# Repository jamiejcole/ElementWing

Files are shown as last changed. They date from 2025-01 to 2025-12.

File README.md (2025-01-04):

## Element Wing - A DIY Command Wing for ETC EOS
This project is an extension of [my previous](https://github.com/jamiejcole/zenith) EOS controller that I made primarily for controlling moving head fixtures, as my Element 2 console doesn't have any encoder wheels.

It's a full sized EOS command wing, featuring the standard ETC key layout and 4 customisable rotary encoders.

Top

### Components used
| Part | Qty | Total ($AUD) | Source |
| --- | --- | --- | --- |
| Gateron Black Switches | 90  | $31.19 | https://www.aliexpress.com/item/1005006376024657.html |
| Blank White XDA PBT Keycaps | 90  | $34.00 | https://www.aliexpress.com/item/1005007683242914.html |
| 1N1418 THT Diodes | 90  | $4.69 | https://www.aliexpress.com/item/32866531235.html |
| MCP23017-E/SO | 1 | $12.59 | https://www.aliexpress.com/item/1005005066054098.html |
| Raspberry Pi Pico* | 1 | $5.63 | https://www.aliexpress.com/item/1005006071676557.html |
| EC11 Rotary Encoders | 4 | $5.20 | https://www.aliexpress.com/item/10000056483250.html |
| Aluminium Knob for Encoders | 4 | $11.39 | https://www.aliexpress.com/item/1005005207623966.html |
| Plastic Heat Set Inserts | 6 | $14.99 | https://www.aliexpress.com/item/1005006472962973.html |
| **Total (excluding PCB)** | | **$119.68**  | |

> Note: The PCB design has the footprint for an official Raspberry Pi Pico with a micro-usb port. I wanted to have USB-C on my board, so I ordered the 16M variant of the above RP2040 board, without checking the pin layout. The board I ordered actually had a slightly different pin layout to the official Pi Pico so I had to make some jumps with short wire on the board, so if you use my PCB design, check which Pico you're ordering first!

## PCB Design
This was the first PCB I've designed, so apologies in advanced if I've made any silly mistakes on it. [Joe Scotto's video](https://www.youtube.com/watch?v=8WXpGTIbxlQ) was helpful for getting started with the design, and [iNimbleSloth's tutorials](https://www.youtube.com/watch?v=XKWoeBwpVNg) were also extremely useful for designing the keyswitch matrix. I ended up ordering the PCB from [JLCPCB](https://jlcpcb.com/) for around $100AUD including shipping, bringing the **total project cost to ~$220 AUD**.

PCB

The PCB consists of a 13x8 diode keyswitch matrix, where each row and column are connected to a GPIO pin on the Pico. The A/B/SW pins of each encoder are connected to a GPIO port on the MCP23017, which is connected to the Pico on the I2C0 interface, with the SDA and SCL lines pulled up to 3v3 with 2.2k resistors.

### Assembly process
After receiving the PCBs, I started designing some test layouts for the Cherry MX style switches. Due to the bed size of my 3D printer, I had to split up each piece into two parts, to be plastic welded together after printing. The CAD design consists of three main parts (each with left/right sides):
1. A plate for the switches to be inserted into prior to soldering to the PCB
2. A main case where the brass heat-set inserts will be put in, allowing the whole unit to be bolted together.
3. A top face-plate/cover with cut-outs for the switches and encoders.

Exploded View

### Custom Keycaps
The keycaps were made using a process I [found here](https://www.youtube.com/watch?v=JR1BwcFyexQ). I used blank white XDA profile PBT keycaps from aliexpress. The process was pretty straightforward:
- Cover each keycap in a thin layer of powder from a toner cartridge. I breathed on the keys before dunking them in the powder (the "hah hah" kind of breathing you do to clean glasses) to get the powder to stick better, then gently blew off the excess.
- Place keycap into a jig mounted to the laser engraver (this was done to ensure the text is consistently in the correct spot).
- Using a 15W diode laser at 380mm/min, 2.1% power and text on a fill layer at 300 lines/inch, etched the dye into the keycaps.
- Cleaned off the excess powder with warm water.




### Programming the microcontroller
I decided to use a Raspberry Pi Pico rather than an Arduino or ESP8266 due to the amount of GPIO pins it had. I downloaded [Earle Philhower's Arduino Core](https://github.com/earlephilhower/arduino-pico) for RP2040 boards and uploaded a test sketch using the Arduino IDE. The Pico uses OSC to communicate with EOS over the USB Serial interface. More info about OSC [can be found here](https://github.com/cnmat/osc). 

The [ETC #lighthack](https://github.com/ETCLabs/lighthack) community also was extremely helpful. Big thanks to [sstaub](https://github.com/CNMAT/OSC/issues/159#issuecomment-2566483844) over on the OSC repo.

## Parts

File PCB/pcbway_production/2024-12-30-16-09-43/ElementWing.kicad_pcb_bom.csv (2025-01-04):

Designator | Quantity | Value | Footprint | Package | MPN | DNP | Mount_Type | Description | Sim.Device | Sim.Pins
D1, D10, D11, D12, D13, D14, D15, D16, D17, D18, D19, D2, D20, D21, D22, D23, D24, D25, D26, D27, D28, D29, D3, D30, D31, D32, D33, D34, D35, D36, D37, D38, D39, D4, D40, D41, D42, D43, D44, D45, D46, D47, D48, D49, D5, D50, D51, D52, D53, D54, D55, D56, D57, D58, D59, D6, D60, D61, D62, D63, D64, D65, D66, D67, D68, D69, D7, D70, D71, D72, D73, D74, D75, D76, D77, D78, D79, D8, D80, D81, D82, D83, D84, D85, D86, D87, D88, D89, D9, D90 | 90 | Diode | Diode_DO-35 |  |  |  | tht | 1N4148 (DO-35) or 1N4148W (SOD-123) | D | 1=K 2=A
EC1, EC2, EC3, EC4 | 4 | RotaryEncoder_Switch | RotaryEncoder_Alps_EC11E-Switch_Vertical_H20mm |  |  |  | tht | Rotary encoder, dual channel, incremental quadrate outputs, with switch
R1, R2 | 2 | 2.2k | R_Axial_DIN0207_L6.3mm_D2.5mm_P10.16mm_Horizontal |  |  |  | tht | Resistor
SW1 | 1 | Displays | MX_PCB_1.00u |  |  |  | tht | Push button switch, normally open, two pins, 45° tilted
SW10 | 1 | MoreSK | MX_PCB_1.00u |  |  |  | tht | Push button switch, normally open, two pins, 45° tilted
SW11 | 1 | Live | MX_PCB_1.00u |  |  |  | tht | Push button switch, normally open, two pins, 45° tilted
SW12 | 1 | Blind | MX_PCB_1.00u |  |  |  | tht | Push button switch, normally open, two pins, 45° tilted
SW13 | 1 | ScrollLock | MX_PCB_1.00u |  |  |  | tht | Push button switch, normally open, two pins, 45° tilted
SW14 | 1 | Macro | MX_PCB_1.00u |  |  |  | tht | Push button switch, normally open, two pins, 45° tilted
SW15 | 1 | Help | MX_PCB_1.00u |  |  |  | tht | Push button switch, normally open, two pins, 45° tilted
SW16 | 1 | Learn | MX_PCB_1.00u |  |  |  | tht | Push button switch, normally open, two pins, 45° tilted
SW17 | 1 | Query | MX_PCB_1.00u |  |  |  | tht | Push button switch, normally open, two pins, 45° tilted
SW18 | 1 | CopyTo | MX_PCB_1.00u |  |  |  | tht | Push button switch, normally open, two pins, 45° tilted
SW19 | 1 | RecallFrom | MX_PCB_1.00u |  |  |  | tht | Push button switch, normally open, two pins, 45° tilted
SW2 | 1 | AddressPatch | MX_PCB_1.00u |  |  |  | tht | Push button switch, normally open, two pins, 45° tilted
SW20 | 1 | LabelNote | MX_PCB_1.00u |  |  |  | tht | Push button switch, normally open, two pins, 45° tilted
SW21 | 1 | EmptyMacro | MX_PCB_1.00u |  |  |  | tht | Push button switch, normally open, two pins, 45° tilted
SW22 | 1 | About | MX_PCB_1.00u |  |  |  | tht | Push button switch, normally open, two pins, 45° tilted
SW23 | 1 | Park | MX_PCB_1.00u |  |  |  | tht | Push button switch, normally open, two pins, 45° tilted
SW24 | 1 | Escape | MX_PCB_1.00u |  |  |  | tht | Push button switch, normally open, two pins, 45° tilted
SW25 | 1 | PageUp | MX_PCB_1.00u |  |  |  | tht | Push button switch, normally open, two pins, 45° tilted
SW26 | 1 | Select | MX_PCB_1.00u |  |  |  | tht | Push button switch, normally open, two pins, 45° tilted
SW27 | 1 | Delete | MX_PCB_1.00u |  |  |  | tht | Push button switch, normally open, two pins, 45° tilted
SW28 | 1 | Path | MX_PCB_1.00u |  |  |  | tht | Push button switch, normally open, two pins, 45° tilted
SW29 | 1 | Effect | MX_PCB_1.00u |  |  |  | tht | Push button switch, normally open, two pins, 45° tilted
SW3 | 1 | MLControls | MX_PCB_1.00u |  |  |  | tht | Push button switch, normally open, two pins, 45° tilted
SW30 | 1 | GoToCue | MX_PCB_1.00u |  |  |  | tht | Push button switch, normally open, two pins, 45° tilted
SW31 | 1 | Block | MX_PCB_1.00u |  |  |  | tht | Push button switch, normally open, two pins, 45° tilted
SW32 | 1 | Assert | MX_PCB_1.00u |  |  |  | tht | Push button switch, normally open, two pins, 45° tilted
SW33 | 1 | Undo | MX_PCB_1.00u |  |  |  | tht | Push button switch, normally open, two pins, 45° tilted
SW34 | 1 | High | MX_PCB_1.00u |  |  |  | tht | Push button switch, normally open, two pins, 45° tilted
SW35 | 1 | Fan | MX_PCB_1.00u |  |  |  | tht | Push button switch, normally open, two pins, 45° tilted
SW36 | 1 | Capture | MX_PCB_1.00u |  |  |  | tht | Push button switch, normally open, two pins, 45° tilted
SW37 | 1 | PageLeft | MX_PCB_1.00u |  |  |  | tht | Push button switch, normally open, two pins, 45° tilted
SW38 | 1 | PageDown | MX_PCB_1.00u |  |  |  | tht | Push button switch, normally open, two pins, 45° tilted
SW39 | 1 | PageRight | MX_PCB_1.00u |  |  |  | tht | Push button switch, normally open, two pins, 45° tilted
SW4 | 1 | S1 | MX_PCB_1.00u |  |  |  | tht | Push button switch, normally open, two pins, 45° tilted
SW40 | 1 | Part | MX_PCB_1.00u |  |  |  | tht | Push button switch, normally open, two pins, 45° tilted
SW41 | 1 | Cue | MX_PCB_1.00u |  |  |  | tht | Push button switch, normally open, two pins, 45° tilted
SW42 | 1 | Record | MX_PCB_1.00u |  |  |  | tht | Push button switch, normally open, two pins, 45° tilted
SW43 | 1 | + | MX_PCB_1.00u |  |  |  | tht | Push button switch, normally open, two pins, 45° tilted
SW44 | 1 | Thru | MX_PCB_1.00u |  |  |  | tht | Push button switch, normally open, two pins, 45° tilted
SW45 | 1 | - | MX_PCB_1.00u |  |  |  | tht | Push button switch, normally open, two pins, 45° tilted
SW46 | 1 | / | MX_PCB_1.00u |  |  |  | tht | Push button switch, normally open, two pins, 45° tilted
SW47 | 1 | Mark | MX_PCB_1.00u |  |  |  | tht | Push button switch, normally open, two pins, 45° tilted
SW48 | 1 | Sneak | MX_PCB_1.00u |  |  |  | tht | Push button switch, normally open, two pins, 45° tilted
SW49 | 1 | SelectLast | MX_PCB_1.00u |  |  |  | tht | Push button switch, normally open, two pins, 45° tilted
SW5 | 1 | S2 | MX_PCB_1.00u |  |  |  | tht | Push button switch, normally open, two pins, 45° tilted
SW50 | 1 | IntensityPalette | MX_PCB_1.00u |  |  |  | tht | Push button switch, normally open, two pins, 45° tilted
SW51 | 1 | FocusPalette | MX_PCB_1.00u |  |  |  | tht | Push button switch, normally open, two pins, 45° tilted
SW52 | 1 | RecordOnly | MX_PCB_1.00u |  |  |  | tht | Push button switch, normally open, two pins, 45° tilted
SW53 | 1 | num7 | MX_PCB_1.00u |  |  |  | tht | Push button switch, normally open, two pins, 45° tilted
SW54 | 1 | num8 | MX_PCB_1.00u |  |  |  | tht | Push button switch, normally open, two pins, 45° tilted
SW55 | 1 | num9 | MX_PCB_1.00u |  |  |  | tht | Push button switch, normally open, two pins, 45° tilted
SW56 | 1 | RemDim | MX_PCB_1.00u |  |  |  | tht | Push button switch, normally open, two pins, 45° tilted
SW57 | 1 | +% | MX_PCB_1.00u |  |  |  | tht | Push button switch, normally open, two pins, 45° tilted
SW58 | 1 | Home | MX_PCB_1.00u |  |  |  | tht | Push button switch, normally open, two pins, 45° tilted
SW59 | 1 | SelectManual | MX_PCB_1.00u |  |  |  | tht | Push button switch, normally open, two pins, 45° tilted
SW6 | 1 | S3 | MX_PCB_1.00u |  |  |  | tht | Push button switch, normally open, two pins, 45° tilted
SW60 | 1 | ColorPalette | MX_PCB_1.00u |  |  |  | tht | Push button switch, normally open, two pins, 45° tilted
SW61 | 1 | BeamPalette | MX_PCB_1.00u |  |  |  | tht | Push button switch, normally open, two pins, 45° tilted
SW62 | 1 | Update | MX_PCB_1.00u |  |  |  | tht | Push button switch, normally open, two pins, 45° tilted
SW63 | 1 | num4 | MX_PCB_1.00u |  |  |  | tht | Push button switch, normally open, two pins, 45° tilted
SW64 | 1 | num5 | MX_PCB_1.00u |  |  |  | tht | Push button switch, normally open, two pins, 45° tilted
SW65 | 1 | num6 | MX_PCB_1.00u |  |  |  | tht | Push button switch, normally open, two pins, 45° tilted
SW66 | 1 | Out | MX_PCB_1.00u |  |  |  | tht | Push button switch, normally open, two pins, 45° tilted
SW67 | 1 | -% | MX_PCB_1.00u |  |  |  | tht | Push button switch, normally open, two pins, 45° tilted
SW68 | 1 | Trace | MX_PCB_1.00u |  |  |  | tht | Push button switch, normally open, two pins, 45° tilted
SW69 | 1 | SelectActive | MX_PCB_1.00u |  |  |  | tht | Push button switch, normally open, two pins, 45° tilted
SW7 | 1 | S4 | MX_PCB_1.00u |  |  |  | tht | Push button switch, normally open, two pins, 45° tilted
SW70 | 1 | Preset | MX_PCB_1.00u |  |  |  | tht | Push button switch, normally open, two pins, 45° tilted
SW71 | 1 | Sub | MX_PCB_1.00u |  |  |  | tht | Push button switch, normally open, two pins, 45° tilted
SW72 | 1 | Group | MX_PCB_1.00u |  |  |  | tht | Push button switch, normally open, two pins, 45° tilted
SW73 | 1 | num1 | MX_PCB_1.00u |  |  |  | tht | Push button switch, normally open, two pins, 45° tilted
SW74 | 1 | num2 | MX_PCB_1.00u |  |  |  | tht | Push button switch, normally open, two pins, 45° tilted
SW75 | 1 | num3 | MX_PCB_1.00u |  |  |  | tht | Push button switch, normally open, two pins, 45° tilted
SW76 | 1 | Full | MX_PCB_1.00u |  |  |  | tht | Push button switch, normally open, two pins, 45° tilted
SW77 | 1 | Level | MX_PCB_1.00u |  |  |  | tht | Push button switch, normally open, two pins, 45° tilted
SW78 | 1 | QOnlyTrack | MX_PCB_1.00u |  |  |  | tht | Push button switch, normally open, two pins, 45° tilted
SW79 | 1 | Last | MX_PCB_1.00u |  |  |  | tht | Push button switch, normally open, two pins, 45° tilted
SW8 | 1 | S5 | MX_PCB_1.00u |  |  |  | tht | Push button switch, normally open, two pins, 45° tilted
SW80 | 1 | Shift | MX_PCB_1.00u |  |  |  | tht | Push button switch, normally open, two pins, 45° tilted
SW81 | 1 | Delay | MX_PCB_1.00u |  |  |  | tht | Push button switch, normally open, two pins, 45° tilted
SW82 | 1 | Time | MX_PCB_1.00u |  |  |  | tht | Push button switch, normally open, two pins, 45° tilted
SW83 | 1 | clear | MX_PCB_1.00u |  |  |  | tht | Push button switch, normally open, two pins, 45° tilted
SW84 | 1 | num0 | MX_PCB_1.00u |  |  |  | tht | Push button switch, normally open, two pins, 45° tilted
SW85 | 1 | num. | MX_PCB_1.00u |  |  |  | tht | Push button switch, normally open, two pins, 45° tilted
SW86 | 1 | At | MX_PCB_1.00u |  |  |  | tht | Push button switch, normally open, two pins, 45° tilted
SW87 | 1 | Enter | MX_PCB_1.00u |  |  |  | tht | Push button switch, normally open, two pins, 45° tilted
SW88 | 1 | Next | MX_PCB_1.00u |  |  |  | tht | Push button switch, normally open, two pins, 45° tilted
SW89 | 1 | StopBack | MX_PCB_1.00u |  |  |  | tht | Push button switch, normally open, two pins, 45° tilted
SW9 | 1 | S6 | MX_PCB_1.00u |  |  |  | tht | Push button switch, normally open, two pins, 45° tilted
SW90 | 1 | Go | MX_PCB_1.00u |  |  |  | tht | Push button switch, normally open, two pins, 45° tilted
U1 | 1 | Raspberry_Pi_Pico | Raspberry_Pi_Pico |  |  |  | tht
U2 | 1 | MCP23017_SO | SOIC-28W_7.5x17.9mm_P1.27mm |  |  |  | smt | 16-bit I/O expander, I2C, interrupts, w pull-ups, SOIC-28

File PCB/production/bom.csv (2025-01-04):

Designator | Footprint | Quantity | Value | LCSC Part #
D1, D10, D11, D12, D13, D14, D15, D16, D17, D18, D19, D2, D20, D21, D22, D23, D24, D25, D26, D27, D28, D29, D3, D30, D31, D32, D33, D34, D35, D36, D37, D38, D39, D4, D40, D41, D42, D43, D44, D45, D46, D47, D48, D49, D5, D50, D51, D52, D53, D54, D55, D56, D57, D58, D59, D6, D60, D61, D62, D63, D64, D65, D66, D67, D68, D69, D7, D70, D71, D72, D73, D74, D75, D76, D77, D78, D79, D8, D80, D81, D82, D83, D84, D85, D86, D87, D88, D89, D9, D90 | Diode_DO-35 | 90 | Diode
EC1, EC2, EC3, EC4 | RotaryEncoder_Alps_EC11E-Switch_Vertical_H20mm | 4 | RotaryEncoder_Switch
R1, R2 | R_Axial_DIN0207_L6.3mm_D2.5mm_P10.16mm_Horizontal | 2 | 2.2k
SW1 | MX_PCB_1.00u | 1 | Displays
SW10 | MX_PCB_1.00u | 1 | MoreSK
SW11 | MX_PCB_1.00u | 1 | Live
SW12 | MX_PCB_1.00u | 1 | Blind
SW13 | MX_PCB_1.00u | 1 | ScrollLock
SW14 | MX_PCB_1.00u | 1 | Macro
SW15 | MX_PCB_1.00u | 1 | Help
SW16 | MX_PCB_1.00u | 1 | Learn
SW17 | MX_PCB_1.00u | 1 | Query
SW18 | MX_PCB_1.00u | 1 | CopyTo
SW19 | MX_PCB_1.00u | 1 | RecallFrom
SW2 | MX_PCB_1.00u | 1 | AddressPatch
SW20 | MX_PCB_1.00u | 1 | LabelNote
SW21 | MX_PCB_1.00u | 1 | EmptyMacro
SW22 | MX_PCB_1.00u | 1 | About
SW23 | MX_PCB_1.00u | 1 | Park
SW24 | MX_PCB_1.00u | 1 | Escape
SW25 | MX_PCB_1.00u | 1 | PageUp
SW26 | MX_PCB_1.00u | 1 | Select
SW27 | MX_PCB_1.00u | 1 | Delete
SW28 | MX_PCB_1.00u | 1 | Path
SW29 | MX_PCB_1.00u | 1 | Effect
SW3 | MX_PCB_1.00u | 1 | MLControls
SW30 | MX_PCB_1.00u | 1 | GoToCue
SW31 | MX_PCB_1.00u | 1 | Block
SW32 | MX_PCB_1.00u | 1 | Assert
SW33 | MX_PCB_1.00u | 1 | Undo
SW34 | MX_PCB_1.00u | 1 | High
SW35 | MX_PCB_1.00u | 1 | Fan
SW36 | MX_PCB_1.00u | 1 | Capture
SW37 | MX_PCB_1.00u | 1 | PageLeft
SW38 | MX_PCB_1.00u | 1 | PageDown
SW39 | MX_PCB_1.00u | 1 | PageRight
SW4 | MX_PCB_1.00u | 1 | S1
SW40 | MX_PCB_1.00u | 1 | Part
SW41 | MX_PCB_1.00u | 1 | Cue
SW42 | MX_PCB_1.00u | 1 | Record
SW43 | MX_PCB_1.00u | 1 | +
SW44 | MX_PCB_1.00u | 1 | Thru
SW45 | MX_PCB_1.00u | 1 | -
SW46 | MX_PCB_1.00u | 1 | /
SW47 | MX_PCB_1.00u | 1 | Mark
SW48 | MX_PCB_1.00u | 1 | Sneak
SW49 | MX_PCB_1.00u | 1 | SelectLast
SW5 | MX_PCB_1.00u | 1 | S2
SW50 | MX_PCB_1.00u | 1 | IntensityPalette
SW51 | MX_PCB_1.00u | 1 | FocusPalette
SW52 | MX_PCB_1.00u | 1 | RecordOnly
SW53 | MX_PCB_1.00u | 1 | num7
SW54 | MX_PCB_1.00u | 1 | num8
SW55 | MX_PCB_1.00u | 1 | num9
SW56 | MX_PCB_1.00u | 1 | RemDim
SW57 | MX_PCB_1.00u | 1 | +%
SW58 | MX_PCB_1.00u | 1 | Home
SW59 | MX_PCB_1.00u | 1 | SelectManual
SW6 | MX_PCB_1.00u | 1 | S3
SW60 | MX_PCB_1.00u | 1 | ColorPalette
SW61 | MX_PCB_1.00u | 1 | BeamPalette
SW62 | MX_PCB_1.00u | 1 | Update
SW63 | MX_PCB_1.00u | 1 | num4
SW64 | MX_PCB_1.00u | 1 | num5
SW65 | MX_PCB_1.00u | 1 | num6
SW66 | MX_PCB_1.00u | 1 | Out
SW67 | MX_PCB_1.00u | 1 | -%
SW68 | MX_PCB_1.00u | 1 | Trace
SW69 | MX_PCB_1.00u | 1 | SelectActive
SW7 | MX_PCB_1.00u | 1 | S4
SW70 | MX_PCB_1.00u | 1 | Preset
SW71 | MX_PCB_1.00u | 1 | Sub
SW72 | MX_PCB_1.00u | 1 | Group
SW73 | MX_PCB_1.00u | 1 | num1
SW74 | MX_PCB_1.00u | 1 | num2
SW75 | MX_PCB_1.00u | 1 | num3
SW76 | MX_PCB_1.00u | 1 | Full
SW77 | MX_PCB_1.00u | 1 | Level
SW78 | MX_PCB_1.00u | 1 | QOnlyTrack
SW79 | MX_PCB_1.00u | 1 | Last
SW8 | MX_PCB_1.00u | 1 | S5
SW80 | MX_PCB_1.00u | 1 | Shift
SW81 | MX_PCB_1.00u | 1 | Delay
SW82 | MX_PCB_1.00u | 1 | Time
SW83 | MX_PCB_1.00u | 1 | clear
SW84 | MX_PCB_1.00u | 1 | num0
SW85 | MX_PCB_1.00u | 1 | num.
SW86 | MX_PCB_1.00u | 1 | At
SW87 | MX_PCB_1.00u | 1 | Enter
SW88 | MX_PCB_1.00u | 1 | Next
SW89 | MX_PCB_1.00u | 1 | StopBack
SW9 | MX_PCB_1.00u | 1 | S6
SW90 | MX_PCB_1.00u | 1 | Go
U1 | Raspberry_Pi_Pico | 1 | Raspberry_Pi_Pico
U2 | SOIC-28W_7.5x17.9mm_P1.27mm | 1 | MCP23017_SO

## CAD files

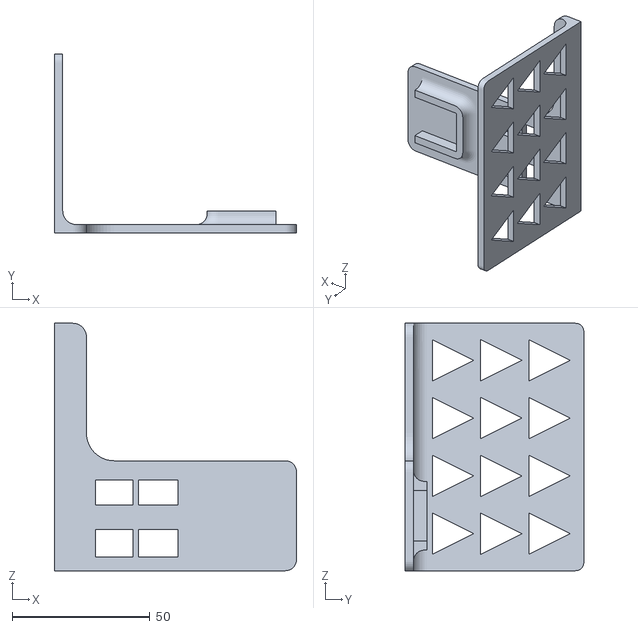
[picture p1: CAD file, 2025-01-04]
3D Models/Keycap Holder.stl
88.0 x 65.0 x 90.0

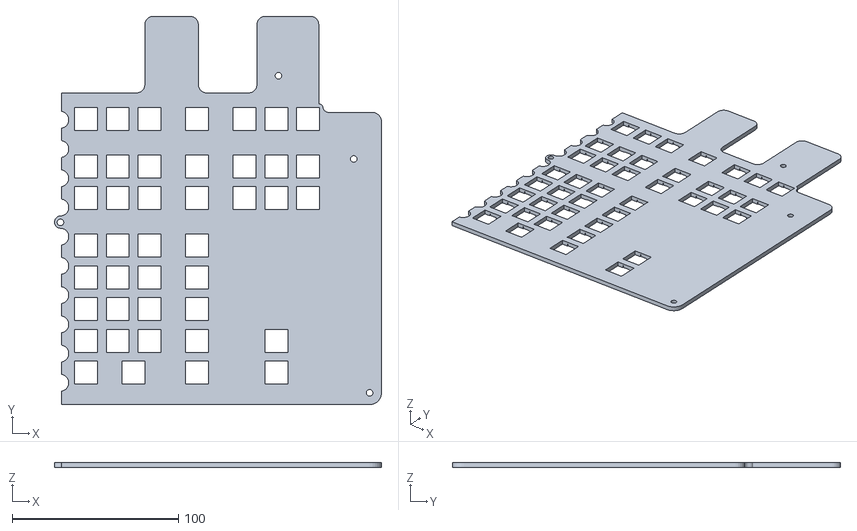
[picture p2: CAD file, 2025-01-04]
3D Models/Keycap Plate Right.stl
196.5 x 233.4 x 3.00

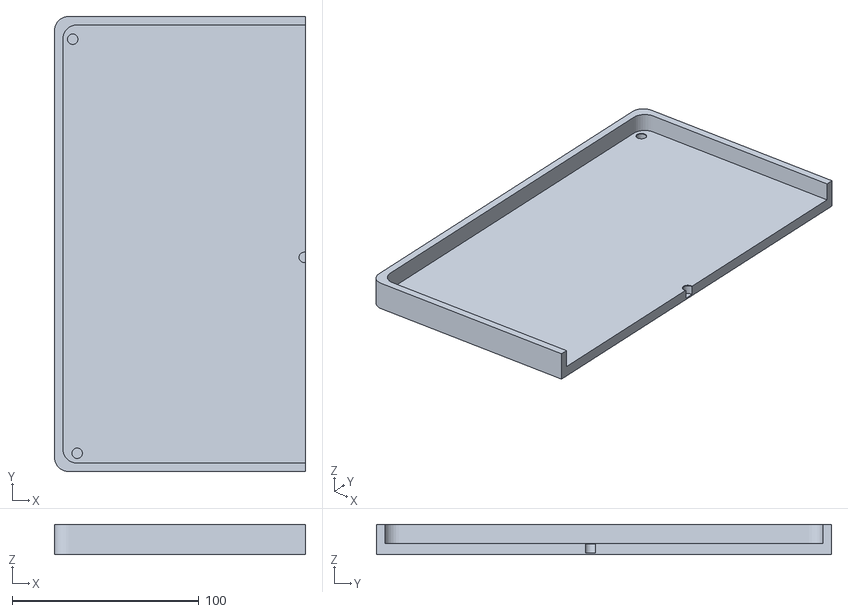
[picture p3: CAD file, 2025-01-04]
3D Models/Case Left.stl
134.3 x 243.4 x 16.2

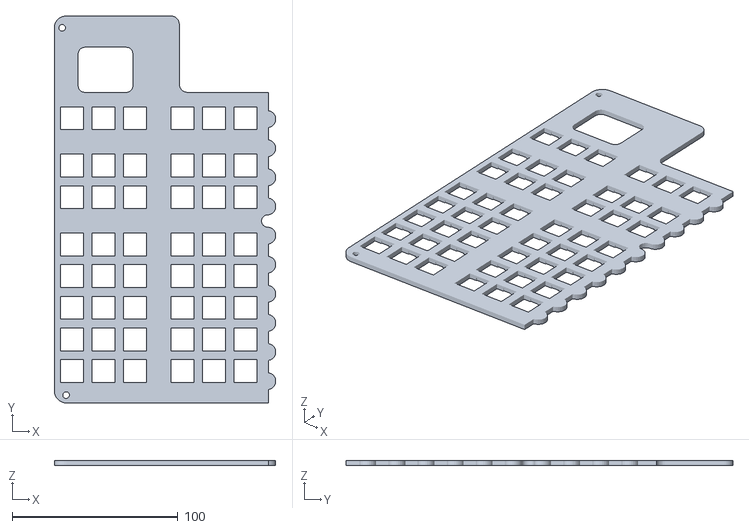
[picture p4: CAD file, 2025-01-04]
3D Models/Keycap Plate Left.stl
133.6 x 233.4 x 3.00

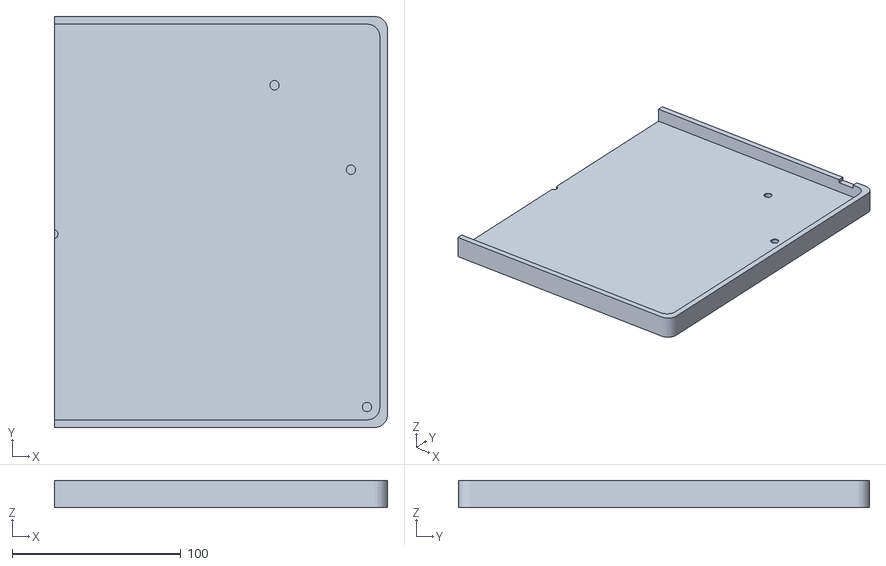
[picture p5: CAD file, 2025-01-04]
3D Models/Case Right.stl
197.2 x 243.4 x 16.2

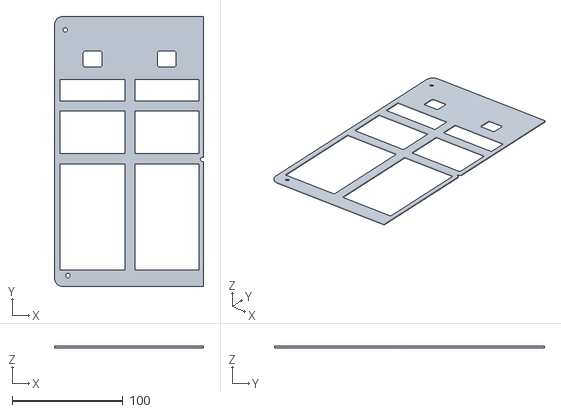
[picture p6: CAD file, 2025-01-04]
3D Models/Face Plate Left.stl
134.3 x 243.4 x 1.50

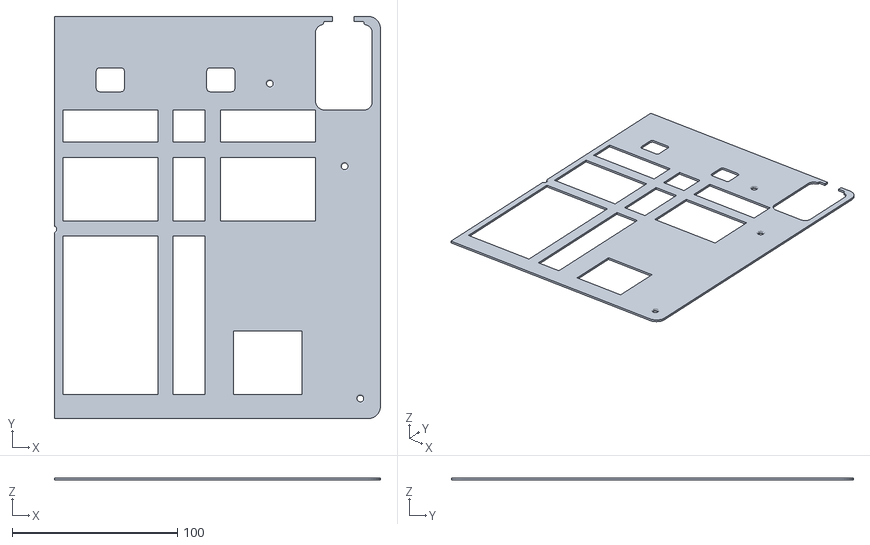
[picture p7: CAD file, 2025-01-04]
3D Models/Face Plate Right.stl
197.2 x 243.4 x 1.50

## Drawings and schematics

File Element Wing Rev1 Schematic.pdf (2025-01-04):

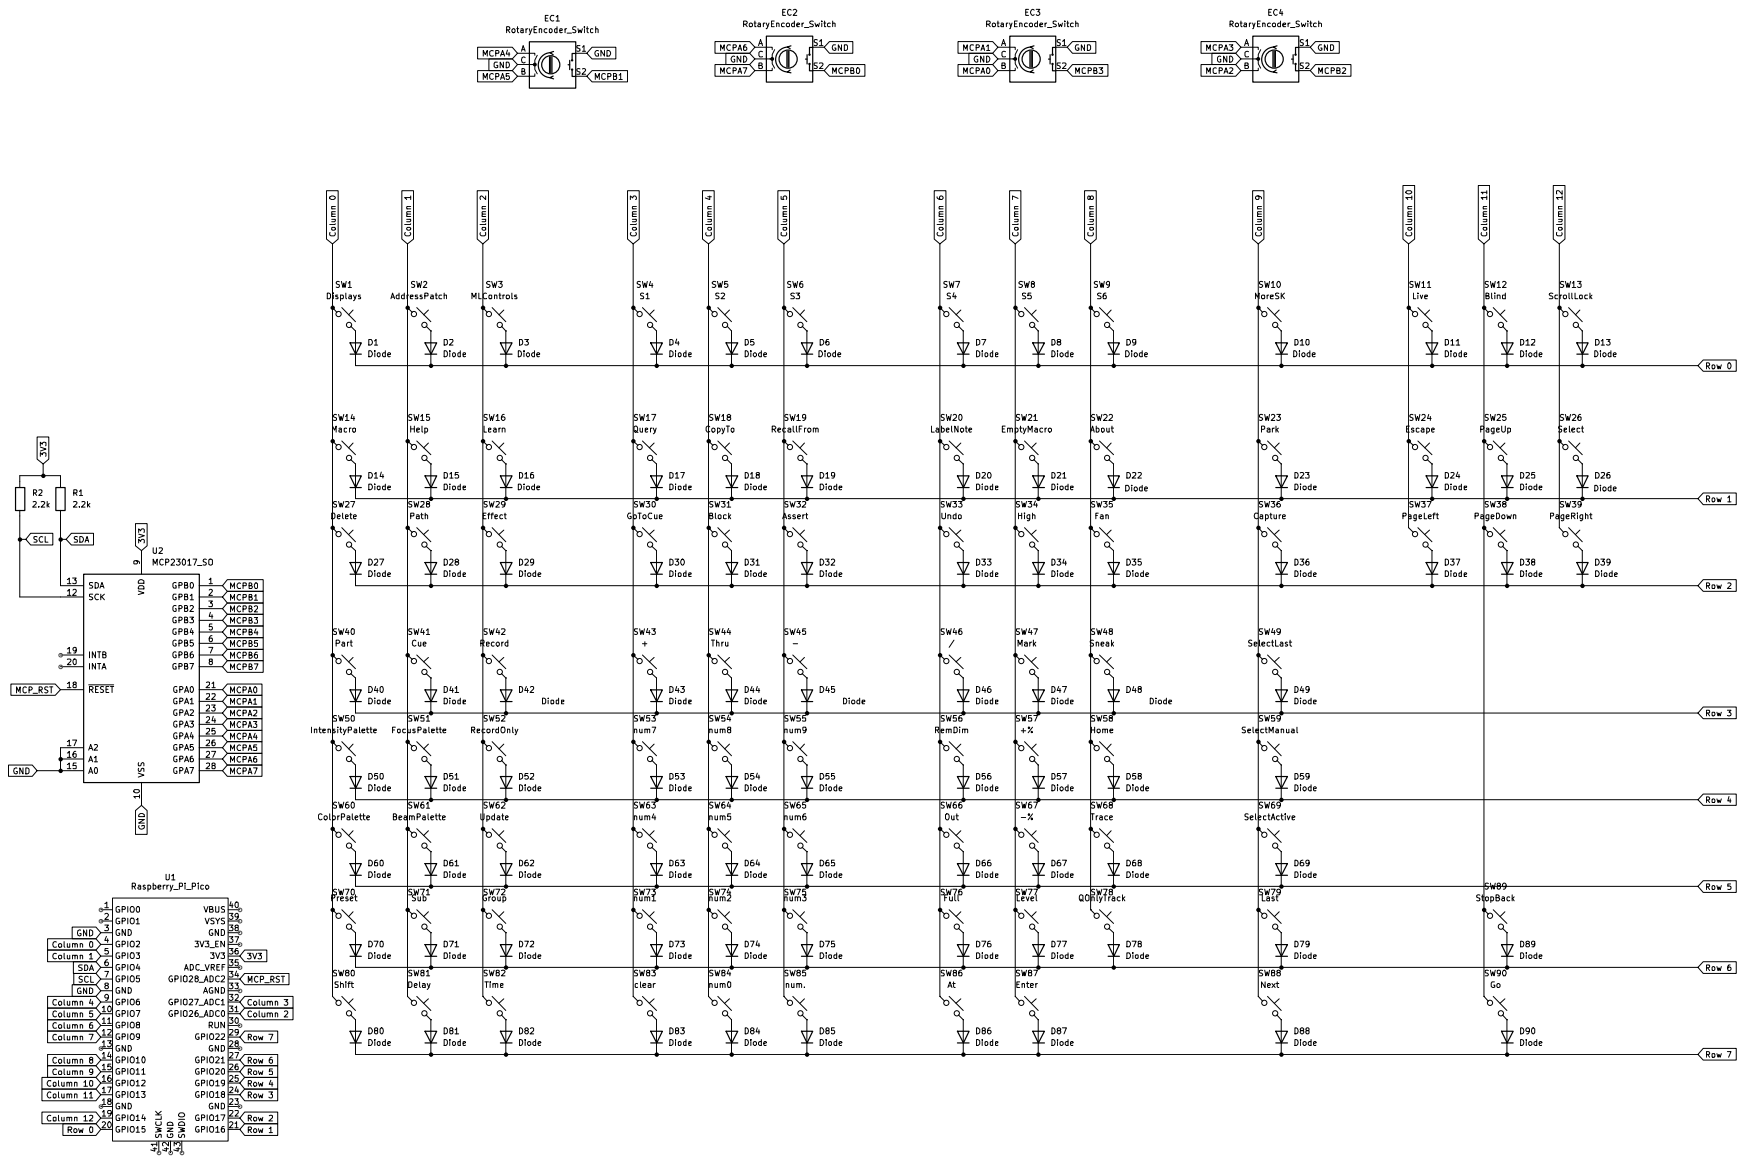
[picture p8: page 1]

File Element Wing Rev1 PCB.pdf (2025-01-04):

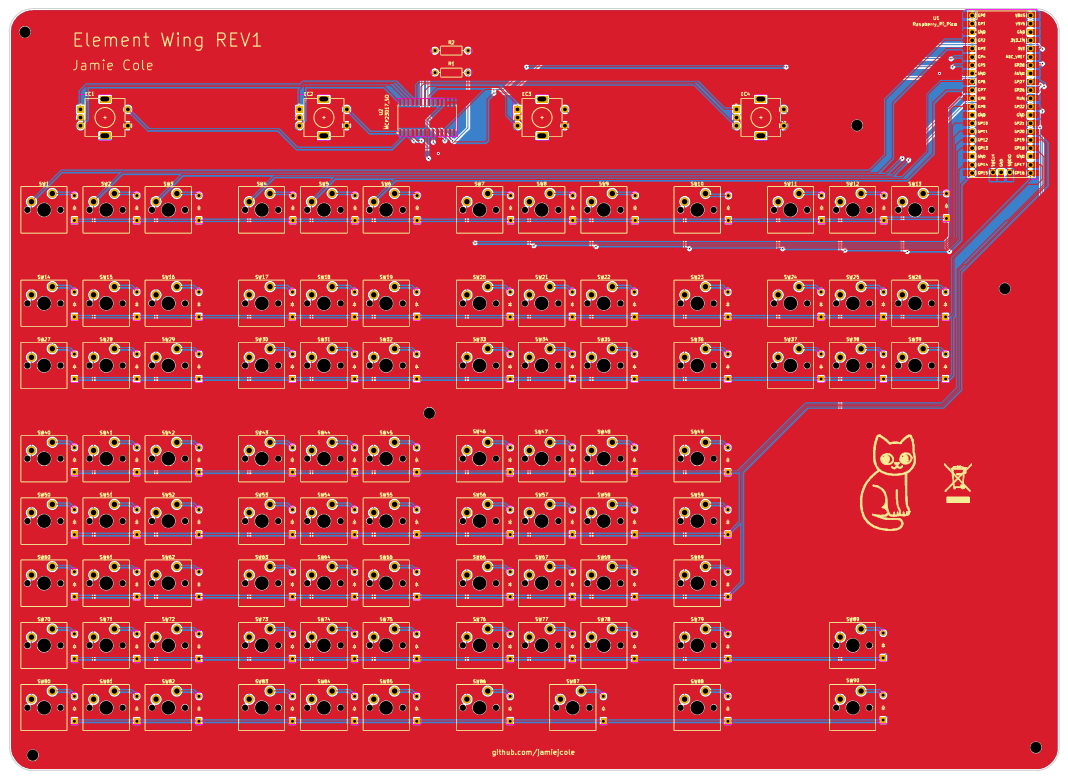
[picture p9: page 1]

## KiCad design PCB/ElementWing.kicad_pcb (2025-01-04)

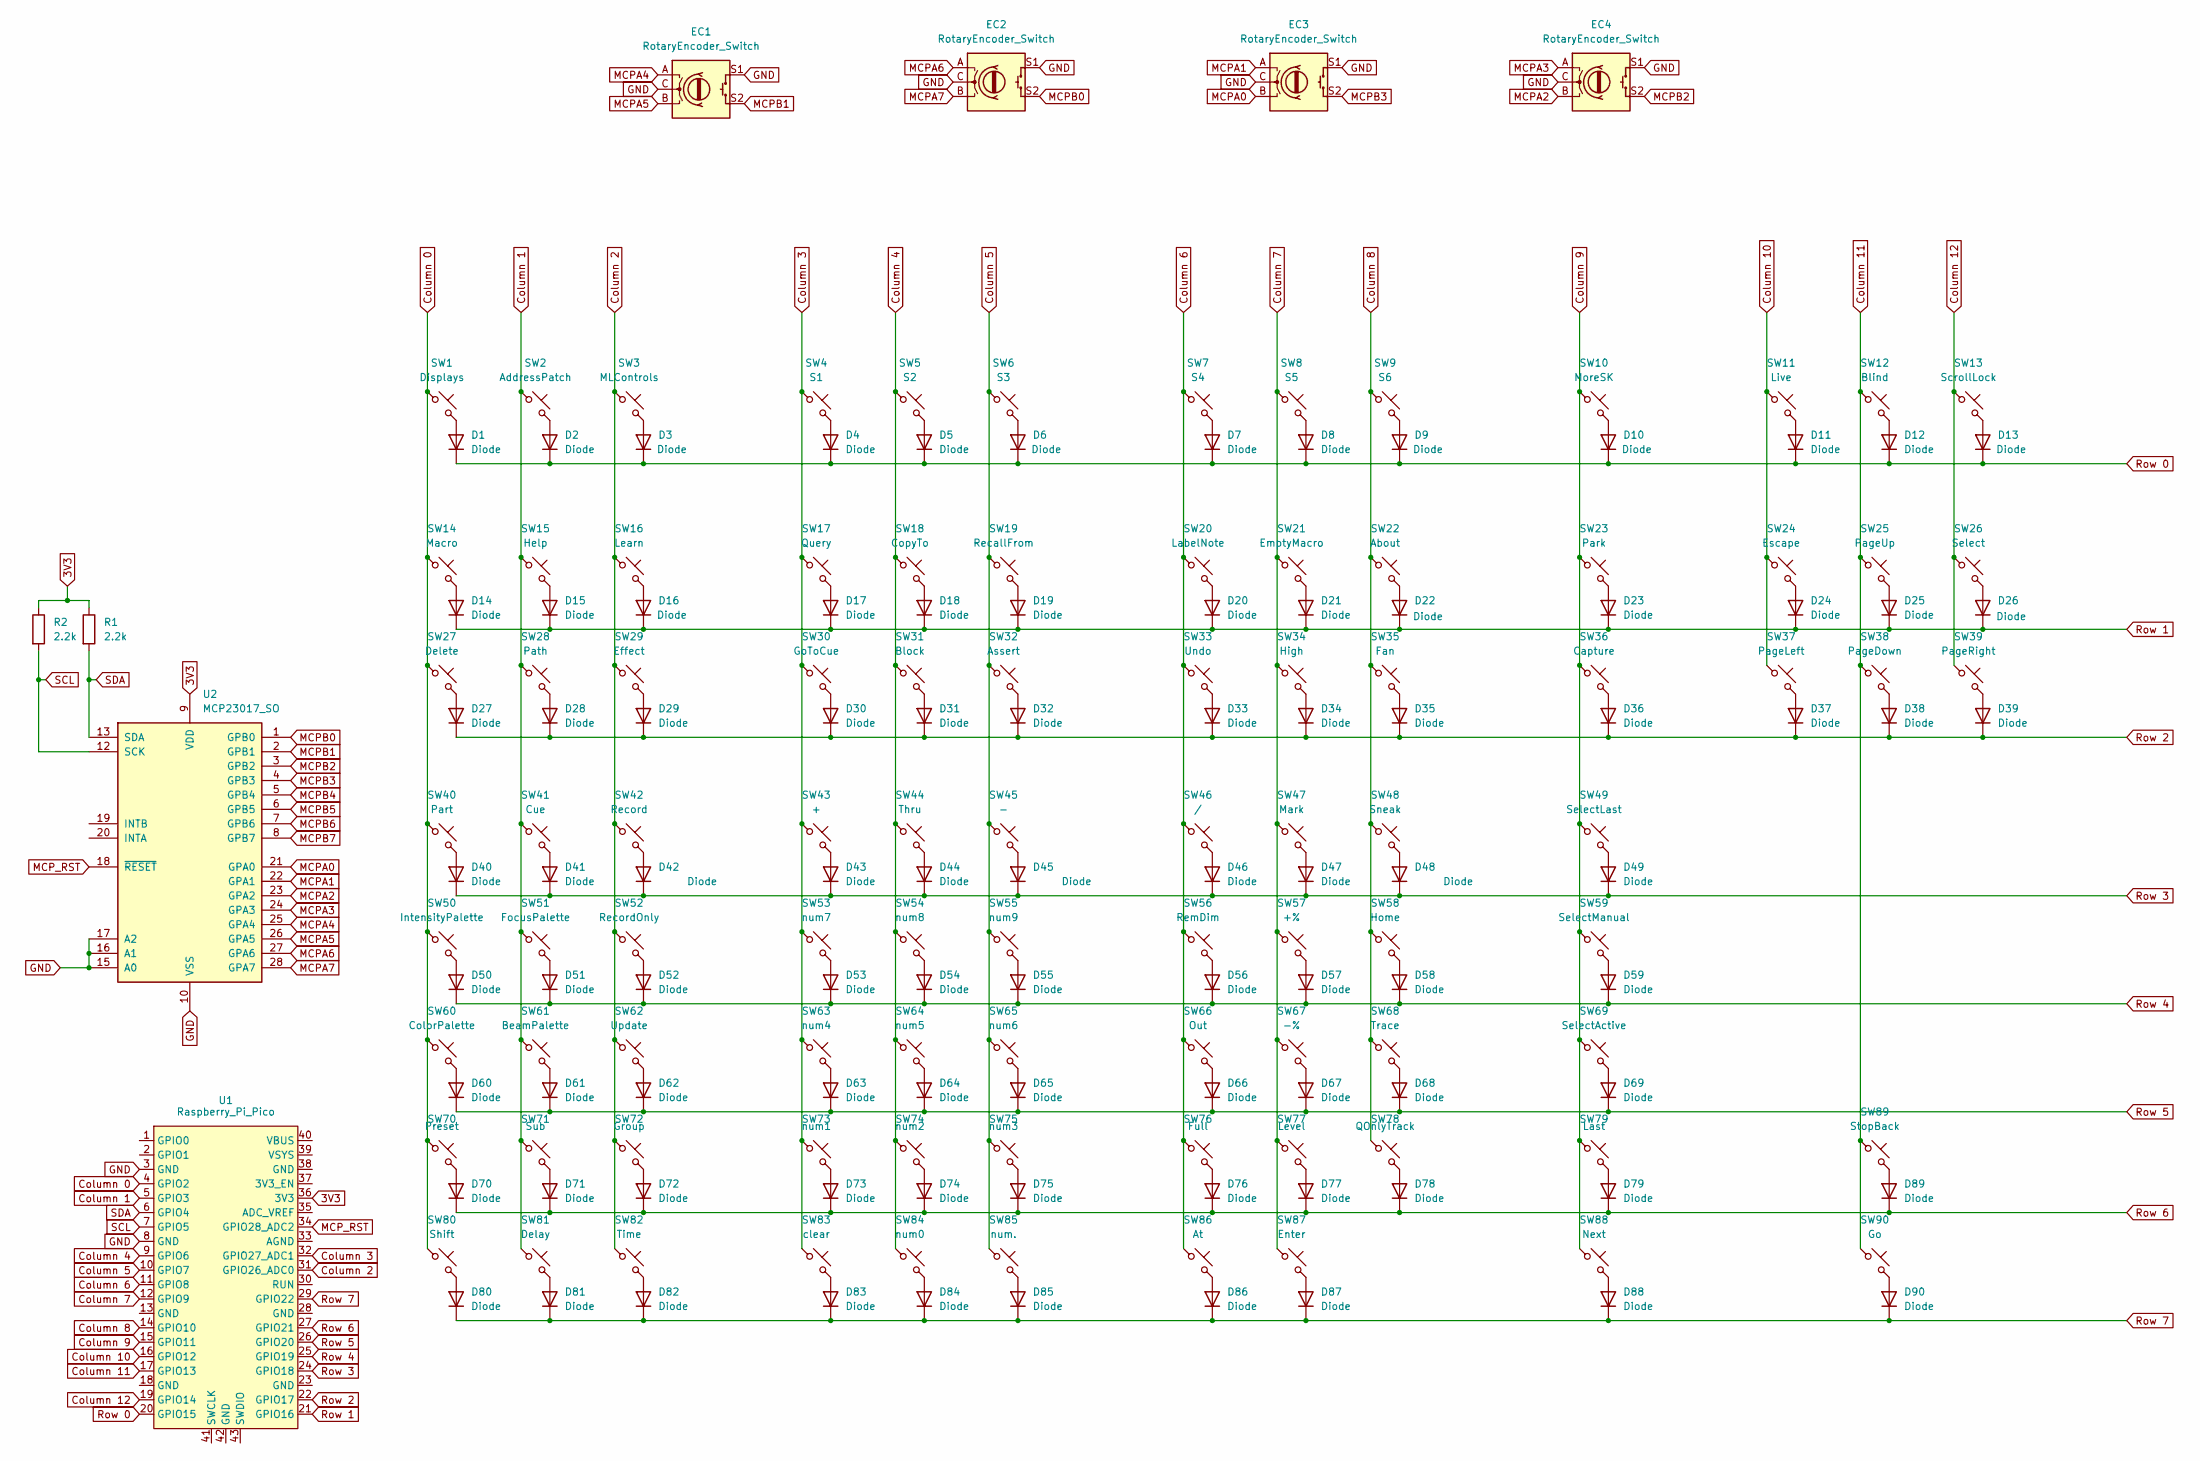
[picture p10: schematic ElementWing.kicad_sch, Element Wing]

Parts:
D1, D2, D3, D4, D5, D6, D7, D8, D9, D10, D11, D12, D13, D14, D15, D16, D17, D18, D19, D20, D21, D22, D23, D24, D25, D26, D27, D28, D29, D30, D31, D32, D33, D34, D35, D36, D37, D38, D39, D40, D41, D42, D43, D44, D45, D46, D47, D48, D49, D50, D51, D52, D53, D54, D55, D56, D57, D58, D59, D60, D61, D62, D63, D64, D65, D66, D67, D68, D69, D70, D71, D72, D73, D74, D75, D76, D77, D78, D79, D80, D81, D82, D83, D84, D85, D86, D87, D88, D89, D90: Diode; Diode_DO-35
EC1, EC2, EC3, EC4: RotaryEncoder_Switch; RotaryEncoder_Alps_EC11E-Switch_Vertical_H20mm
R1, R2: 2.2k; R_Axial_DIN0207_L6.3mm_D2.5mm_P10.16mm_Horizontal
SW1: Displays; MX_PCB_1.00u
SW2: AddressPatch; MX_PCB_1.00u
SW3: MLControls; MX_PCB_1.00u
SW4: S1; MX_PCB_1.00u
SW5: S2; MX_PCB_1.00u
SW6: S3; MX_PCB_1.00u
SW7: S4; MX_PCB_1.00u
SW8: S5; MX_PCB_1.00u
SW9: S6; MX_PCB_1.00u
SW10: MoreSK; MX_PCB_1.00u
SW11: Live; MX_PCB_1.00u
SW12: Blind; MX_PCB_1.00u
SW13: ScrollLock; MX_PCB_1.00u
SW14: Macro; MX_PCB_1.00u
SW15: Help; MX_PCB_1.00u
SW16: Learn; MX_PCB_1.00u
SW17: Query; MX_PCB_1.00u
SW18: CopyTo; MX_PCB_1.00u
SW19: RecallFrom; MX_PCB_1.00u
SW20: LabelNote; MX_PCB_1.00u
SW21: EmptyMacro; MX_PCB_1.00u
SW22: About; MX_PCB_1.00u
SW23: Park; MX_PCB_1.00u
SW24: Escape; MX_PCB_1.00u
SW25: PageUp; MX_PCB_1.00u
SW26: Select; MX_PCB_1.00u
SW27: Delete; MX_PCB_1.00u
SW28: Path; MX_PCB_1.00u
SW29: Effect; MX_PCB_1.00u
SW30: GoToCue; MX_PCB_1.00u
SW31: Block; MX_PCB_1.00u
SW32: Assert; MX_PCB_1.00u
SW33: Undo; MX_PCB_1.00u
SW34: High; MX_PCB_1.00u
SW35: Fan; MX_PCB_1.00u
SW36: Capture; MX_PCB_1.00u
SW37: PageLeft; MX_PCB_1.00u
SW38: PageDown; MX_PCB_1.00u
SW39: PageRight; MX_PCB_1.00u
SW40: Part; MX_PCB_1.00u
SW41: Cue; MX_PCB_1.00u
SW42: Record; MX_PCB_1.00u
SW43: +; MX_PCB_1.00u
SW44: Thru; MX_PCB_1.00u
SW45: -; MX_PCB_1.00u
SW46: /; MX_PCB_1.00u
SW47: Mark; MX_PCB_1.00u
SW48: Sneak; MX_PCB_1.00u
SW49: SelectLast; MX_PCB_1.00u
SW50: IntensityPalette; MX_PCB_1.00u
SW51: FocusPalette; MX_PCB_1.00u
SW52: RecordOnly; MX_PCB_1.00u
SW53: num7; MX_PCB_1.00u
SW54: num8; MX_PCB_1.00u
SW55: num9; MX_PCB_1.00u
SW56: RemDim; MX_PCB_1.00u
SW57: +%; MX_PCB_1.00u
SW58: Home; MX_PCB_1.00u
SW59: SelectManual; MX_PCB_1.00u
SW60: ColorPalette; MX_PCB_1.00u
SW61: BeamPalette; MX_PCB_1.00u
SW62: Update; MX_PCB_1.00u
SW63: num4; MX_PCB_1.00u
SW64: num5; MX_PCB_1.00u
SW65: num6; MX_PCB_1.00u
SW66: Out; MX_PCB_1.00u
SW67: -%; MX_PCB_1.00u
SW68: Trace; MX_PCB_1.00u
SW69: SelectActive; MX_PCB_1.00u
SW70: Preset; MX_PCB_1.00u
SW71: Sub; MX_PCB_1.00u
SW72: Group; MX_PCB_1.00u
SW73: num1; MX_PCB_1.00u
SW74: num2; MX_PCB_1.00u
SW75: num3; MX_PCB_1.00u
SW76: Full; MX_PCB_1.00u
SW77: Level; MX_PCB_1.00u
SW78: QOnlyTrack; MX_PCB_1.00u
SW79: Last; MX_PCB_1.00u
SW80: Shift; MX_PCB_1.00u
SW81: Delay; MX_PCB_1.00u
SW82: Time; MX_PCB_1.00u
SW83: clear; MX_PCB_1.00u
SW84: num0; MX_PCB_1.00u
SW85: num.; MX_PCB_1.00u
SW86: At; MX_PCB_1.00u
SW87: Enter; MX_PCB_1.00u
SW88: Next; MX_PCB_1.00u
SW89: StopBack; MX_PCB_1.00u
SW90: Go; MX_PCB_1.00u
U1: Raspberry_Pi_Pico
U2: MCP23017_SO; SOIC-28W_7.5x17.9mm_P1.27mm

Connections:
3V3: R1.1, R2.1, U1.36 (3V3), U2.9 (VDD)
Column 0: SW1.1, SW14.1, SW27.1, SW40.1, SW50.1, SW60.1, SW70.1, SW80.1, U1.4 (GPIO2)
Column 1: SW2.1, SW15.1, SW28.1, SW41.1, SW51.1, SW61.1, SW71.1, SW81.1, U1.5 (GPIO3)
Column 2: SW3.1, SW16.1, SW29.1, SW42.1, SW52.1, SW62.1, SW72.1, SW82.1, U1.31 (GPIO26_ADC0)
Column 3: SW4.1, SW17.1, SW30.1, SW43.1, SW53.1, SW63.1, SW73.1, SW83.1, U1.32 (GPIO27_ADC1)
Column 4: SW5.1, SW18.1, SW31.1, SW44.1, SW54.1, SW64.1, SW74.1, SW84.1, U1.9 (GPIO6)
Column 5: SW6.1, SW19.1, SW32.1, SW45.1, SW55.1, SW65.1, SW75.1, SW85.1, U1.10 (GPIO7)
Column 6: SW7.1, SW20.1, SW33.1, SW46.1, SW56.1, SW66.1, SW76.1, SW86.1, U1.11 (GPIO8)
Column 7: SW8.1, SW21.1, SW34.1, SW47.1, SW57.1, SW67.1, SW77.1, SW87.1, U1.12 (GPIO9)
Column 8: SW9.1, SW22.1, SW35.1, SW48.1, SW58.1, SW68.1, SW78.1, U1.14 (GPIO10)
Column 9: SW10.1, SW23.1, SW36.1, SW49.1, SW59.1, SW69.1, SW79.1, SW88.1, U1.15 (GPIO11)
Column 10: SW11.1, SW24.1, SW37.1, U1.16 (GPIO12)
Column 11: SW12.1, SW25.1, SW38.1, SW89.1, SW90.1, U1.17 (GPIO13)
Column 12: SW13.1, SW26.1, SW39.1, U1.19 (GPIO14)
GND: EC1.C, EC1.S1, EC2.C, EC2.S1, EC3.C, EC3.S1, EC4.C, EC4.S1, U1.3 (GND), U1.8 (GND), U2.10 (VSS), U2.15 (A0), U2.16 (A1), U2.17 (A2)
MCPA0: EC3.B, U2.21 (GPA0)
MCPA1: EC3.A, U2.22 (GPA1)
MCPA2: EC4.B, U2.23 (GPA2)
MCPA3: EC4.A, U2.24 (GPA3)
MCPA4: EC1.A, U2.25 (GPA4)
MCPA5: EC1.B, U2.26 (GPA5)
MCPA6: EC2.A, U2.27 (GPA6)
MCPA7: EC2.B, U2.28 (GPA7)
MCPB0: EC2.S2, U2.1 (GPB0)
MCPB1: EC1.S2, U2.2 (GPB1)
MCPB2: EC4.S2, U2.3 (GPB2)
MCPB3: EC3.S2, U2.4 (GPB3)
MCPB4: U2.5 (GPB4)
MCPB5: U2.6 (GPB5)
MCPB6: U2.7 (GPB6)
MCPB7: U2.8 (GPB7)
MCP_RST: U1.34 (GPIO28_ADC2), U2.18 (~RESET)
unnamed: D1.2 (A), SW1.2
unnamed: D2.2 (A), SW2.2
unnamed: D3.2 (A), SW3.2
unnamed: D4.2 (A), SW4.2
unnamed: D5.2 (A), SW5.2
unnamed: D6.2 (A), SW6.2
unnamed: D7.2 (A), SW7.2
unnamed: D8.2 (A), SW8.2
unnamed: D9.2 (A), SW9.2
unnamed: D10.2 (A), SW10.2
unnamed: D11.2 (A), SW11.2
unnamed: D12.2 (A), SW12.2
unnamed: D13.2 (A), SW13.2
unnamed: D14.2 (A), SW14.2
unnamed: D15.2 (A), SW15.2
unnamed: D16.2 (A), SW16.2
unnamed: D17.2 (A), SW17.2
unnamed: D18.2 (A), SW18.2
unnamed: D19.2 (A), SW19.2
unnamed: D20.2 (A), SW20.2
unnamed: D21.2 (A), SW21.2
unnamed: D22.2 (A), SW22.2
unnamed: D23.2 (A), SW23.2
unnamed: D24.2 (A), SW24.2
unnamed: D25.2 (A), SW25.2
unnamed: D26.2 (A), SW26.2
unnamed: D27.2 (A), SW27.2
unnamed: D28.2 (A), SW28.2
unnamed: D29.2 (A), SW29.2
unnamed: D30.2 (A), SW30.2
unnamed: D31.2 (A), SW31.2
unnamed: D32.2 (A), SW32.2
unnamed: D33.2 (A), SW33.2
unnamed: D34.2 (A), SW34.2
unnamed: D35.2 (A), SW35.2
unnamed: D36.2 (A), SW36.2
unnamed: D37.2 (A), SW37.2
unnamed: D38.2 (A), SW38.2
unnamed: D39.2 (A), SW39.2
unnamed: D40.2 (A), SW40.2
unnamed: D41.2 (A), SW41.2
unnamed: D42.2 (A), SW42.2
unnamed: D43.2 (A), SW43.2
unnamed: D44.2 (A), SW44.2
unnamed: D45.2 (A), SW45.2
unnamed: D46.2 (A), SW46.2
unnamed: D47.2 (A), SW47.2
unnamed: D48.2 (A), SW48.2
unnamed: D49.2 (A), SW49.2
unnamed: D50.2 (A), SW50.2
unnamed: D51.2 (A), SW51.2
unnamed: D52.2 (A), SW52.2
unnamed: D53.2 (A), SW53.2
unnamed: D54.2 (A), SW54.2
unnamed: D55.2 (A), SW55.2
unnamed: D56.2 (A), SW56.2
unnamed: D57.2 (A), SW57.2
unnamed: D58.2 (A), SW58.2
unnamed: D59.2 (A), SW59.2
unnamed: D60.2 (A), SW60.2
unnamed: D61.2 (A), SW61.2
unnamed: D62.2 (A), SW62.2
unnamed: D63.2 (A), SW63.2
unnamed: D64.2 (A), SW64.2
unnamed: D65.2 (A), SW65.2
unnamed: D66.2 (A), SW66.2
unnamed: D67.2 (A), SW67.2
unnamed: D68.2 (A), SW68.2
unnamed: D69.2 (A), SW69.2
unnamed: D70.2 (A), SW70.2
unnamed: D71.2 (A), SW71.2
unnamed: D72.2 (A), SW72.2
unnamed: D73.2 (A), SW73.2
unnamed: D74.2 (A), SW74.2
unnamed: D75.2 (A), SW75.2
unnamed: D76.2 (A), SW76.2
unnamed: D77.2 (A), SW77.2
unnamed: D78.2 (A), SW78.2
unnamed: D79.2 (A), SW79.2
unnamed: D80.2 (A), SW80.2
unnamed: D81.2 (A), SW81.2
unnamed: D82.2 (A), SW82.2
unnamed: D83.2 (A), SW83.2
unnamed: D84.2 (A), SW84.2
unnamed: D85.2 (A), SW85.2
unnamed: D86.2 (A), SW86.2
unnamed: D87.2 (A), SW87.2
unnamed: D88.2 (A), SW88.2
unnamed: D89.2 (A), SW89.2
unnamed: D90.2 (A), SW90.2
Row 0: D1.1 (K), D2.1 (K), D3.1 (K), D4.1 (K), D5.1 (K), D6.1 (K), D7.1 (K), D8.1 (K), D9.1 (K), D10.1 (K), D11.1 (K), D12.1 (K), D13.1 (K), U1.20 (GPIO15)
Row 1: D14.1 (K), D15.1 (K), D16.1 (K), D17.1 (K), D18.1 (K), D19.1 (K), D20.1 (K), D21.1 (K), D22.1 (K), D23.1 (K), D24.1 (K), D25.1 (K), D26.1 (K), U1.21 (GPIO16)
Row 2: D27.1 (K), D28.1 (K), D29.1 (K), D30.1 (K), D31.1 (K), D32.1 (K), D33.1 (K), D34.1 (K), D35.1 (K), D36.1 (K), D37.1 (K), D38.1 (K), D39.1 (K), U1.22 (GPIO17)
Row 3: D40.1 (K), D41.1 (K), D42.1 (K), D43.1 (K), D44.1 (K), D45.1 (K), D46.1 (K), D47.1 (K), D48.1 (K), D49.1 (K), U1.24 (GPIO18)
Row 4: D50.1 (K), D51.1 (K), D52.1 (K), D53.1 (K), D54.1 (K), D55.1 (K), D56.1 (K), D57.1 (K), D58.1 (K), D59.1 (K), U1.25 (GPIO19)
Row 5: D60.1 (K), D61.1 (K), D62.1 (K), D63.1 (K), D64.1 (K), D65.1 (K), D66.1 (K), D67.1 (K), D68.1 (K), D69.1 (K), U1.26 (GPIO20)
Row 6: D70.1 (K), D71.1 (K), D72.1 (K), D73.1 (K), D74.1 (K), D75.1 (K), D76.1 (K), D77.1 (K), D78.1 (K), D79.1 (K), D89.1 (K), U1.27 (GPIO21)
Row 7: D80.1 (K), D81.1 (K), D82.1 (K), D83.1 (K), D84.1 (K), D85.1 (K), D86.1 (K), D87.1 (K), D88.1 (K), D90.1 (K), U1.29 (GPIO22)
SCL: R2.2, U1.7 (GPIO5), U2.12 (SCK)
SDA: R1.2, U1.6 (GPIO4), U2.13 (SDA)

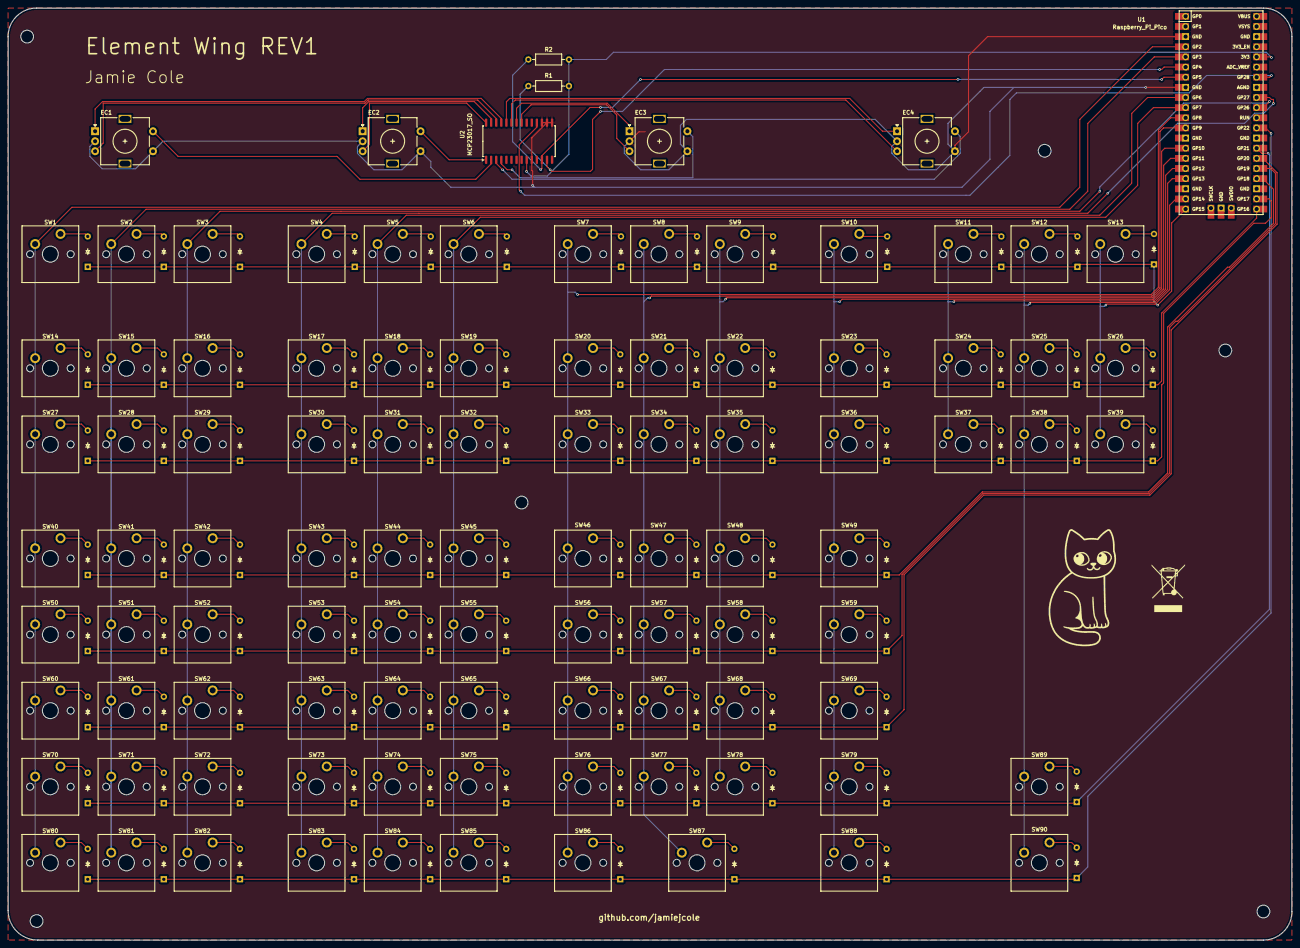
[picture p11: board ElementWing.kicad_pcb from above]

Board: 2 copper layers, 321.5 x 233.4 mm, 188 parts (0 on the bottom side), 128 nets.

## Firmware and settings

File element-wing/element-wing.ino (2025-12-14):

// ETC EOS Command Wing
// https://github.com/jamiejcole/ElementWing
// 4th Jan 2024

#include <Wire.h>
#include "Adafruit_MCP23017.h"
#include "Rotary.h"
#include "RotaryEncOverMCP.h"
#include <OSCBoards.h>
#include <OSCBundle.h>
#include <OSCData.h>
#include <OSCMatch.h>
#include <OSCMessage.h>
#include <OSCTiming.h>
#include "hardware/watchdog.h"

// EOS OSC Serial
#ifdef BOARD_HAS_USB_SERIAL
  #include <SLIPEncodedUSBSerial.h>
    SLIPEncodedUSBSerial SLIPSerial(thisBoardsSerialUSB);
  #else
  #include <SLIPEncodedSerial.h>
    SLIPEncodedSerial SLIPSerial(Serial);
#endif

// Constant definitions
#define MCP_SDA 20
#define MCP_SCL 5

#define MCP_EC1_A 4
#define MCP_EC1_B 5
#define MCP_EC2_A 6
#define MCP_EC2_B 7
#define MCP_EC3_A 1
#define MCP_EC3_B 0
#define MCP_EC4_A 3
#define MCP_EC4_B 2

#define NUM_ENCODER_BUTTONS 4
#define OSC_BUF_MAX_SIZE 512
#define PING_AFTER_IDLE_INTERVAL 2500
#define TIMEOUT_AFTER_IDLE_INTERVAL 5000

enum ConsoleType
{
  ConsoleNone,
  ConsoleEos,
};

// Function Declarations
void RotaryEncoderChanged(bool clockwise, int id);
void sendOSCMessage(const String &address, float value);
void sendKeyPress(const String &key, int shiftMod = -1);
void sendEncoderMovement(int page, int encoder, float ticks);

// Variables
const int encoderButtons[NUM_ENCODER_BUTTONS] = {9, 8, 11, 10};
bool encoderButtonState[NUM_ENCODER_BUTTONS];
unsigned long lastDebounceTime[NUM_ENCODER_BUTTONS];
const unsigned long debounceDelay = 80; // debounce delay
int shiftState = 0;

const String HANDSHAKE_QUERY = "ETCOSC?";
const String HANDSHAKE_REPLY = "OK";

ConsoleType connectedToConsole = ConsoleNone;
unsigned long lastMessageRxTime = 0;
bool timeoutPingSent = false;

Adafruit_MCP23017 mcp;

RotaryEncOverMCP rotaryEncoders[] = {
  RotaryEncOverMCP(&mcp, MCP_EC1_A, MCP_EC1_B, &RotaryEncoderChanged, 1),
  RotaryEncOverMCP(&mcp, MCP_EC2_A, MCP_EC2_B, &RotaryEncoderChanged, 2),
  RotaryEncOverMCP(&mcp, MCP_EC3_A, MCP_EC3_B, &RotaryEncoderChanged, 3),
  RotaryEncOverMCP(&mcp, MCP_EC4_A, MCP_EC4_B, &RotaryEncoderChanged, 4),
};

constexpr int numEncoders = (int)(sizeof(rotaryEncoders) / sizeof(*rotaryEncoders));

const char* encoderFunctions[][4] = {
  {"pan", "tilt", "zoom", "edge"}, // page 1
  {"iris", "Gobo_Select", "Gobo_Select_2", "Gobo_Index/Speed"} // page 2
};

int currentPage = 0;
int goboMode = 63.0;
const int TICK_AMOUNT = 2;

// Key switch matrix definitions
const byte ROWS = 8;
const byte COLS = 13;

const char* keys[ROWS][COLS] = {
  {"displays", "address", "open_ml_controls", "softkey_1", "softkey_2", "softkey_3", "softkey_4", "softkey_5", "softkey_6", "more_softkeys", "live", "blind", "staging_mode"},
  {"macro", "help", "learn", "query", "copy_to", "recall_from", "label", "macro_1", "about", "park", "escape", "page_up", "select"},
  {"delete", "path", "effect", "go_to_cue", "block", "assert", "undo", "highlight", "fan_", "capture", "page_left", "page_down", "page_right"},
  {"part", "cue", "record", "+", "thru", "-", "\\", "mark", "sneak", "select_last"},
  {"intensity_palette", "focus_palette", "record_only", "7", "8", "9", "rem_dim", "+%", "home", "select_manual"},
  {"color_palette", "beam_palette", "update", "4", "5", "6", "out", "-%", "trace", "select_active"},
  {"preset", "sub", "group", "1", "2", "3", "full", "level", "cueonlytrack", "last", "", "stop"},
  {"shift", "delay", "time", "clear_cmd", "0", ".", "at", "enter", "", "next", "", "go_0"}
};


byte rowPins[ROWS] = {17, 18, 19, 21, 22, 23, 24, 25};
byte colPins[COLS] = {3, 4, 27, 28, 7, 8, 9, 10, 12, 11, 13, 14, 16};

bool keyState[ROWS][COLS];
unsigned long keyLastChange[ROWS][COLS];
const unsigned long keyDebounceDelay = 40;

void sendOscMessage(const String &address, float value) {
  OSCMessage msg(address.c_str());
  msg.add(value);
  SLIPSerial.beginPacket();
  msg.send(SLIPSerial);
  SLIPSerial.endPacket();
}

void issueEosSubscribes() {
  // Adding a filter to only listen for pings
  OSCMessage filter("/eos/filter/add");
  // filter.add("/eos/out/param/*");
  filter.add("/eos/out/ping");

  SLIPSerial.beginPacket();
  filter.send(SLIPSerial);
  SLIPSerial.endPacket();
}

void parseOscMessage(String &msg) {
  // If it's a handshake string, reply
  if (msg.indexOf(HANDSHAKE_QUERY) != -1) {
    SLIPSerial.beginPacket();
    SLIPSerial.write((const uint8_t*)HANDSHAKE_REPLY.c_str(), (size_t)HANDSHAKE_REPLY.length());
    SLIPSerial.endPacket();

    // Subscribe to ping message
    issueEosSubscribes();
  }
}

void sendOSCMessage(const String &address, float value) {
  OSCMessage msg(address.c_str());
  msg.add(value);
  SLIPSerial.beginPacket();
  msg.send(SLIPSerial);
  SLIPSerial.endPacket();
}

void sendKeyPress(const String &key, int shiftMod) {
  String msg = "/eos/key/" + key;
  if (shiftMod == 1) {
    sendOSCMessage(msg, 1.0);
    shiftState = 1;
  }
  else if (shiftMod == 0) {
    sendOSCMessage(msg, 0.0);
    shiftState = 0;
  }
  else {
    OSCMessage keyMsg(msg.c_str());
    SLIPSerial.beginPacket();
    keyMsg.send(SLIPSerial);
    SLIPSerial.endPacket();
  }
}

void RotaryEncoderChanged(bool clockwise, int id) {
  Serial.println(
    "Encoder " + String(id) + ": "
    + (clockwise ? String("clockwise") : String("counter-clock-wise"))
  );
  sendEncoderMovement(currentPage, id - 1, (clockwise ? -TICK_AMOUNT : TICK_AMOUNT));
}

void sendEncoderMovement(int page, int encoder, float ticks) {
  float sentTicks = ticks;
  if (page == 1 && (encoder == 1 || encoder == 2)) {
    sentTicks *= 4;
  }
  if (page == 1 && encoder == 3) {
    String wheelMsg("/eos/wheel/coarse/Gobo_Index\\Speed");
    sendOSCMessage(wheelMsg, sentTicks);
  }
  else {
    String wheelMsg("/eos/wheel");
    wheelMsg.concat("/coarse/");
    wheelMsg.concat(encoderFunctions[page][encoder]);
    sendOSCMessage(wheelMsg, sentTicks);
  }
}

void pollKeyMatrix() {
  // static array to remember the last raw read for each key across invocations
  static bool lastRaw[ROWS][COLS];
  static bool inited = false;
  unsigned long now = millis();

  // Initialize lastRaw on first call to the current stable state
  if (!inited) {
    for (int r = 0; r < ROWS; r++) {
      for (int c = 0; c < COLS; c++) {
        lastRaw[r][c] = false;
      }
    }
    inited = true;
  }

  for (int row = 0; row < ROWS; row++) {
    // Activate the current row
    digitalWrite(rowPins[row], LOW);

    // give the row output a short time to settle before reading columns
    delayMicroseconds(5);

    for (int col = 0; col < COLS; col++) {
      bool isPressed = (digitalRead(colPins[col]) == LOW);

      if (isPressed != lastRaw[row][col]) {
        lastRaw[row][col] = isPressed;
        keyLastChange[row][col] = now;
      }

      if (isPressed != keyState[row][col] &&
          (now - keyLastChange[row][col]) >= keyDebounceDelay) {

        keyState[row][col] = isPressed;

        if (isPressed) {
          sendKeyPress(keys[row][col],
                       keys[row][col] == "shift" ? 1 : -1);
        } else if (keys[row][col] == "shift") {
          sendKeyPress(keys[row][col], 0);
        }
      }
    }

    // Deactivate the current row
    digitalWrite(rowPins[row], HIGH);
  }
}

void pollAllEncoders() {
  uint16_t gpioAB = mcp.readGPIOAB();
  for (int i = 0; i < numEncoders; i++) {
    rotaryEncoders[i].feedInput(gpioAB);
  }
}

void pollEncoderButtons() {
  for (int i = 0; i < NUM_ENCODER_BUTTONS; i++) {
    bool isPressed = !mcp.digitalRead(encoderButtons[i]);
    unsigned long currentTime = millis();

    // Check for debounce
    if (isPressed != encoderButtonState[i] && (currentTime - lastDebounceTime[i] > debounceDelay)) {
      lastDebounceTime[i] = currentTime; // Update debounce timer

      if (isPressed) {
        if (i == 0) {
          currentPage = 0;
        }
        else if (i == 1) {
          currentPage = 1;
        }
        else if (i == 3) {
          // sendOSC to change Gobo Mode to Index (Gobo_Mode 63) or Rot (Gobo_Mode 191)
          String wheelMsg("/eos/wheel/coarse/Gobo_Mode");
          float value = goboMode == 63.0 ? 191.0 : 63.0;
          sendOSCMessage(wheelMsg, value);
          goboMode = value;
        }
      }
      encoderButtonState[i] = isPressed;
    }
  }
}

void setupMatrixPins() {
  for (int r = 0; r < ROWS; r++) {
    pinMode(rowPins[r], OUTPUT);
    digitalWrite(rowPins[r], HIGH);  // idle
  }

  for (int c = 0; c < COLS; c++) {
    pinMode(colPins[c], INPUT_PULLUP);
  }
}

void setup() {
  watchdog_enable(3000, true);
  Wire.setSDA(MCP_SDA);
  Wire.setSCL(MCP_SCL);
  Wire.begin();
  Wire.setClock(400000);
  mcp.begin();

  // Initalize encoders
  for (int i = 0; i < numEncoders; i++) {
    rotaryEncoders[i].init();
  }

  setupMatrixPins();

  // Initialize encoder button pins with internal pull-ups
  for (int i = 0; i < NUM_ENCODER_BUTTONS; i++) {
    mcp.pinMode(encoderButtons[i], INPUT);
    mcp.pullUp(encoderButtons[i], HIGH);
    encoderButtonState[i] = false;
    lastDebounceTime[i] = 0;
  }

  // Initialize all key states to "released"
  for (int row = 0; row < ROWS; row++) {
    for (int col = 0; col < COLS; col++) {
      keyLastChange[row][col] = 0;
      keyState[row][col] = false;
    }
  }

  delay(500);

  SLIPSerial.begin(115200);
  while (!Serial) {
    // Wait for serial to connect
    delay(10);
    continue;
  }

  // Send initial handshake reply
  SLIPSerial.beginPacket();
  SLIPSerial.write((const uint8_t*)HANDSHAKE_REPLY.c_str(), (size_t)HANDSHAKE_REPLY.length());
  SLIPSerial.endPacket();

  issueEosSubscribes();

  delay(100);
}

void loop() {
  pollAllEncoders();
  pollEncoderButtons();
  pollKeyMatrix();
  watchdog_update();

  // Checking if any OSC commands have come from EOS
  static String curMsg;
  int size;
  size = SLIPSerial.available();
  if (size > 0)
  {
    while (size--)
      curMsg += (char)(SLIPSerial.read());
  }
  if (SLIPSerial.endofPacket())
  {
    parseOscMessage(curMsg);
    lastMessageRxTime = millis();
    timeoutPingSent = false;
    curMsg = String();
  }

  // Checking for timeouts
  if (lastMessageRxTime > 0)
  {
    unsigned long diff = millis() - lastMessageRxTime;
    if (diff > TIMEOUT_AFTER_IDLE_INTERVAL)
    {
      connectedToConsole = ConsoleNone;
      lastMessageRxTime = 0;
      timeoutPingSent = false;
    }

    // Send a ping after 2.5s
    if (!timeoutPingSent && diff > PING_AFTER_IDLE_INTERVAL)
    {
      OSCMessage ping("/eos/ping");
      ping.add("ElementWing_hello");
      SLIPSerial.beginPacket();
      ping.send(SLIPSerial);
      SLIPSerial.endPacket();
      timeoutPingSent = true;
    }
  }
}

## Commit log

2025-01-04 fixed OSC commands and updated readme
    [element-test-2.ino]
2025-01-04 added CAD and PCB designs
    [ElementWing.kicad_pcb, ElementWing.kicad_pcb_bom.csv, ElementWing.kicad_pcb_positions.csv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]
2025-01-04 Added STLs
    [Case Left.stl, Case Right.stl, Face Plate Left.stl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]
2025-12-14 fixed blind on startup
    [element-wing.ino]
